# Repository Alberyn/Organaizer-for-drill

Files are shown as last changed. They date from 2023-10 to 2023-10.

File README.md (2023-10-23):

# Organaizer-for-drill

### Исследование

**Дано**: Сверла различных диаметров от 1.5 до 10 мм, общее количество превышает 40 штук.

Исследование началось с просмотра различных вариантов органайзеров в интернета (маркетплейсы, подделки от любителей) посредством ввода в поисковике "органайзер для сверл". Анализ результатов вывел типичную структуру для любого найденого органайзера - создание отдельного отверстия для каждого сверла. Рассмотрим несколько типичных органайзера, отличающихся друг от друга, разве что формой.

| Существующие решения | Достоинства | Недостатки |
|---|---|---|
|[Круглый держатель для сверл](https://darxton.ru/catalog_item/organayzer-dlya-svyerl-0-13-mm-100-predmetov/)| Много отверстий, занимает меньше места чем прямоугольная форма| Долгое время печати, нет возможности использования фанеры |
|[Органайзер с крышкой](https://aliexpress.ru/item/1005006088691748.html?sku_id=12000035679458737&spm=.search_results.2.7a9a45b48rbVsu)| Простота, защита от пыли | Не хватает отсеков |
|[Органайзер из фанеры с гравировкой для диаметров](https://ishooter.ru/product/organaizer-pod-sverla-10-99-mm-red-force-derevo.html) | Минимализм и простота | Используемый вариант, неудобный захват сверл|

**Вывод**: Так как количество сверл в будущем изменится и заранее узнать их диаметр невозможно, то было решено доработать дизайн из "Органайзер из фанеры с гравировкой для диаметров" с удобным захватом и регулируемым размером отверстий

### Доска вдохновения

[Miro. Organaizer-for-drill](https://miro.com/app/board/uXjVNaxHn4c=/?share_link_id=504908036010)

### Скетчинг

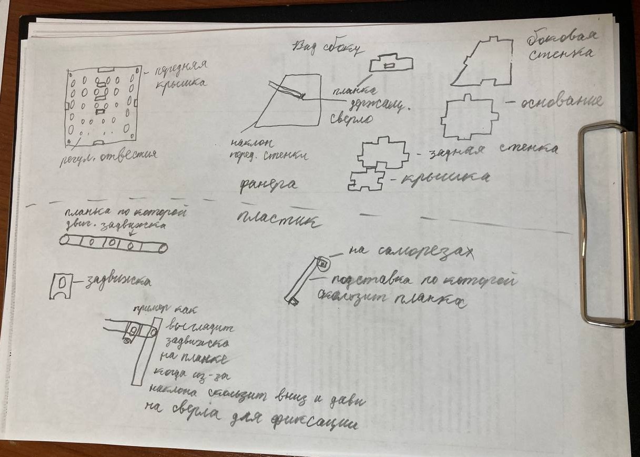
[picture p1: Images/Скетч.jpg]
sketch


Рисунок 1 - Наброски вида органайзера и его сборочных деталей

**Решение задачи**: Каркас из фанеры, мелкие (внутрение) детали из пластика, соединение будет осуществляться через саморезы.

### Моделирование и подготовка к печати

**Программное обеспечение**: SolidWorks, CorelDraw, Prusia Slicer

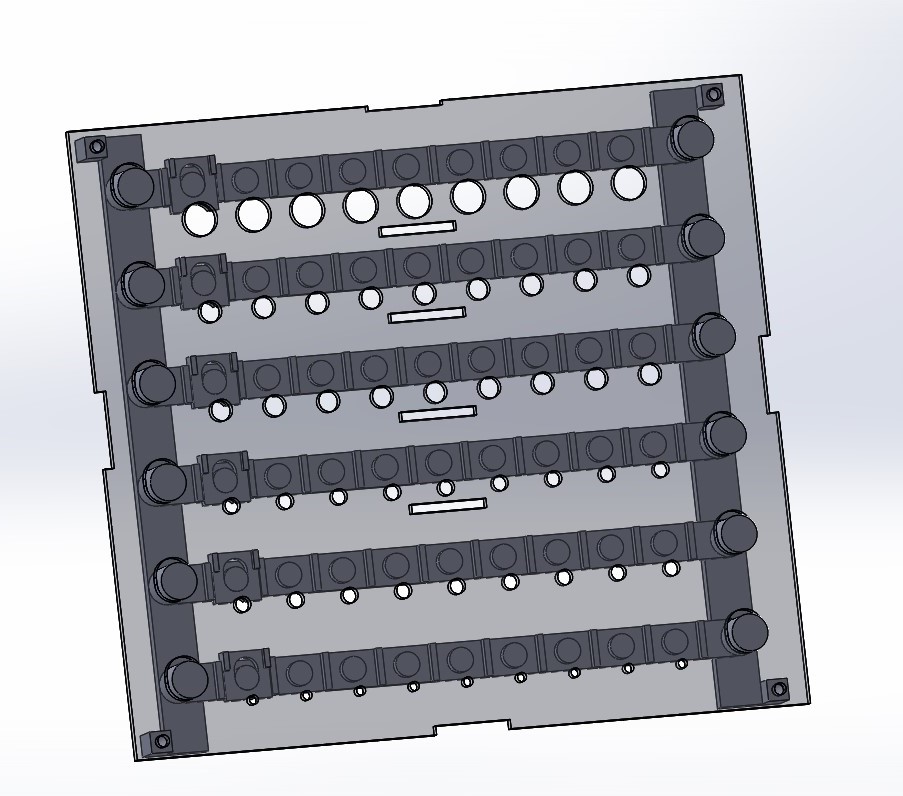
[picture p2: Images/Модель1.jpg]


Пример работы задвижки

Рисунок 2 - Трехмерная модель передней крышки с пластиковыми деталями

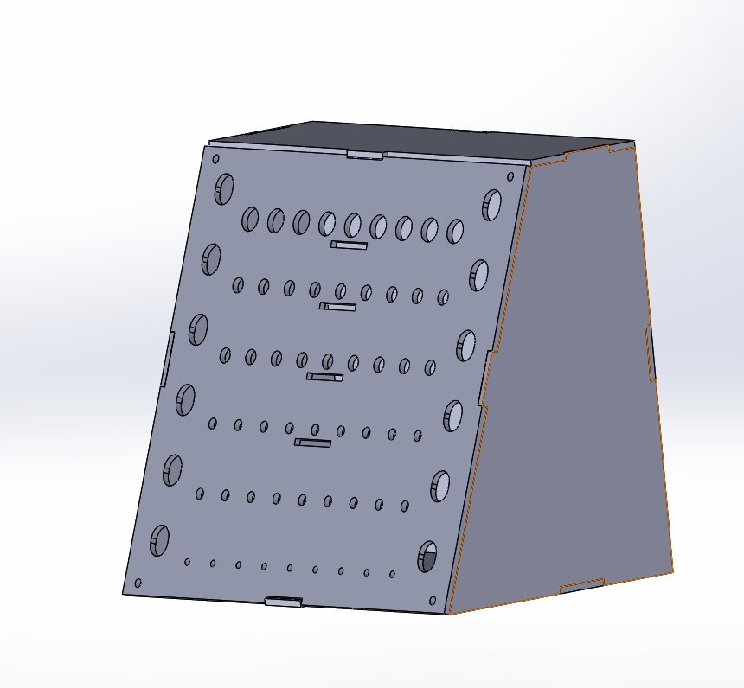
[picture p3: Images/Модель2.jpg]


Рисунок 3 - Трехмерная модель внешнего корпуса

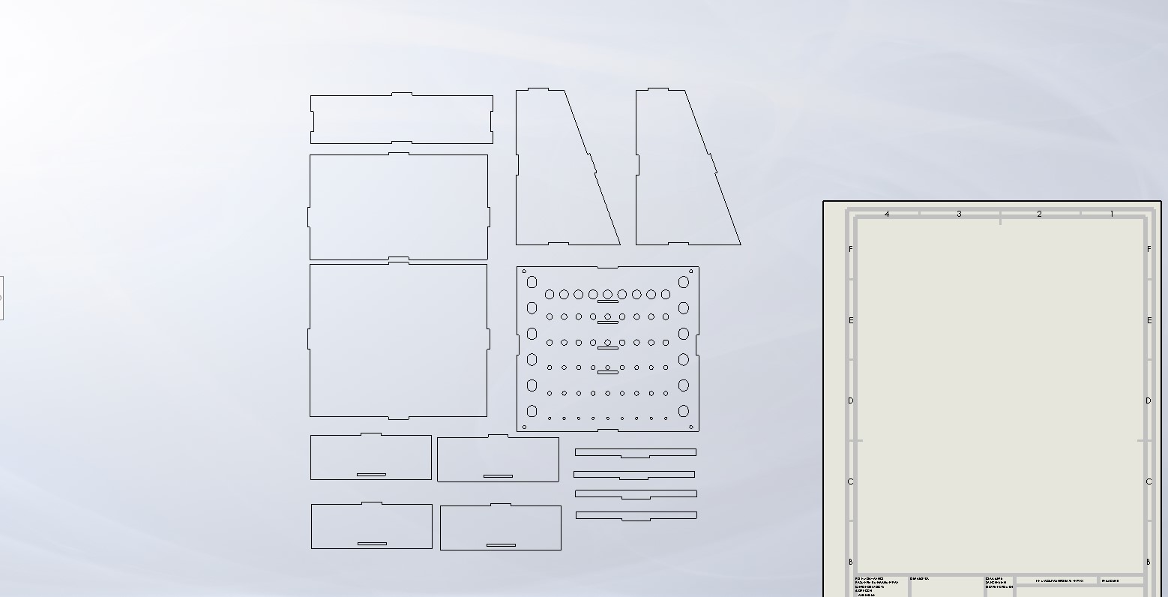
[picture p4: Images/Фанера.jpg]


Рисунок 4 - Чертеж каркаса из фанеры

Все модели для корпуса и деталей сделаны в программе Solidworks, модели корпуса экспортированы в формат DWG для последующего открытия в CorelDraw и отправки на печать. Модели деталей экспортированы в формат STL для последующего слайсинга в программе Prusa Slicer.

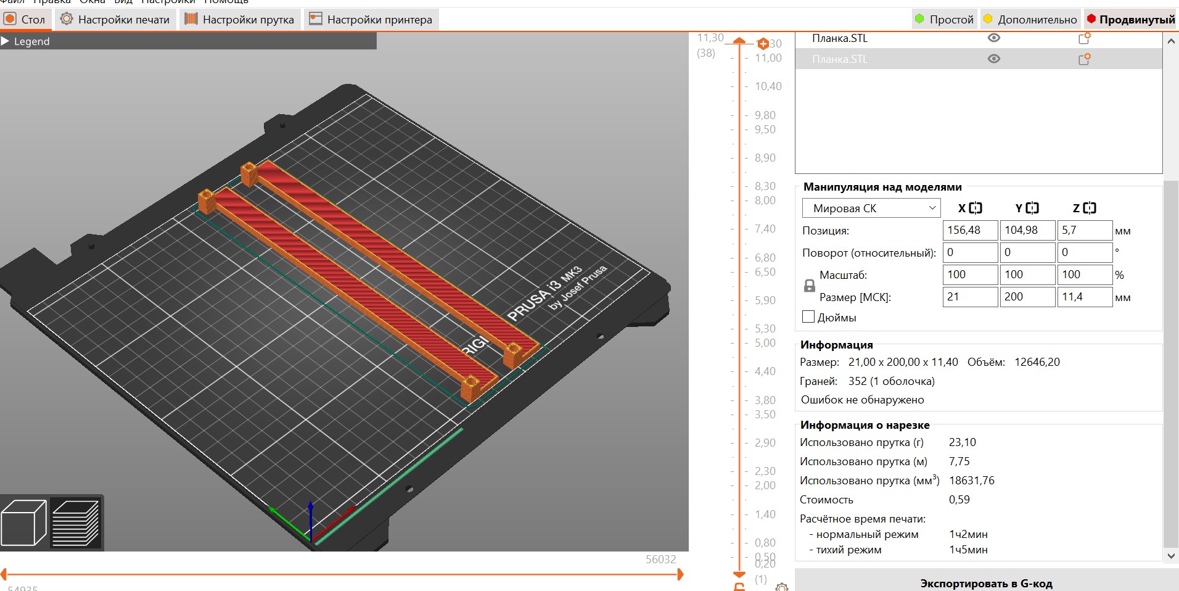
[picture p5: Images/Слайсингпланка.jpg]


Рисунок 5 - Создание G-кода для принтера

### Изготовление и сборка

| Материалы | Применение | Стоимость* | Оборудование | Время изготовления | 
|---|---|---|---|---|
|Лист фанеры 3 мм  | Каркас | 330 руб | Лазерный станок GCC Spirit GLS100 |6 минут |
|Filament PLA  | Внутрение детали | 145 руб | 3D-принтер Prusa i3 MK3 |6:20 часов |

*рассчитано, исходя из указанной в интернете стоимости материала

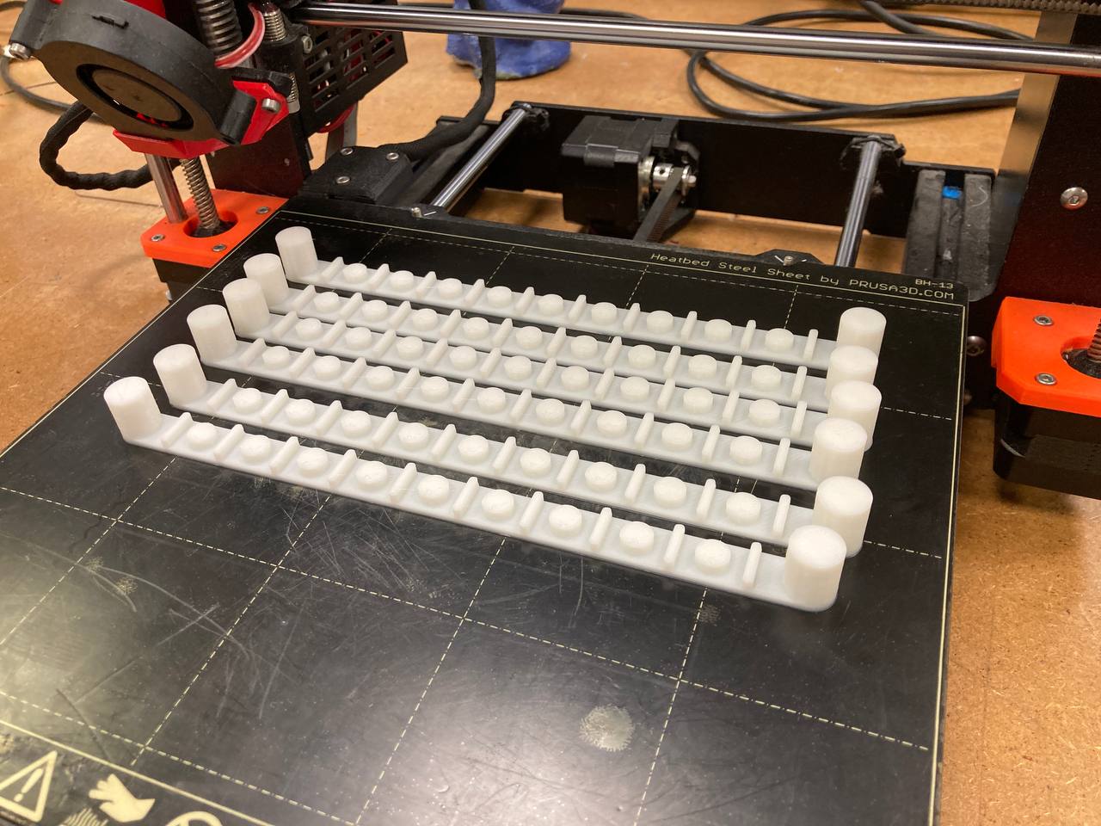
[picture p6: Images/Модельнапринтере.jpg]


Рисунок 6 - Полученный элемент органайзера с помощью 3D-принтера

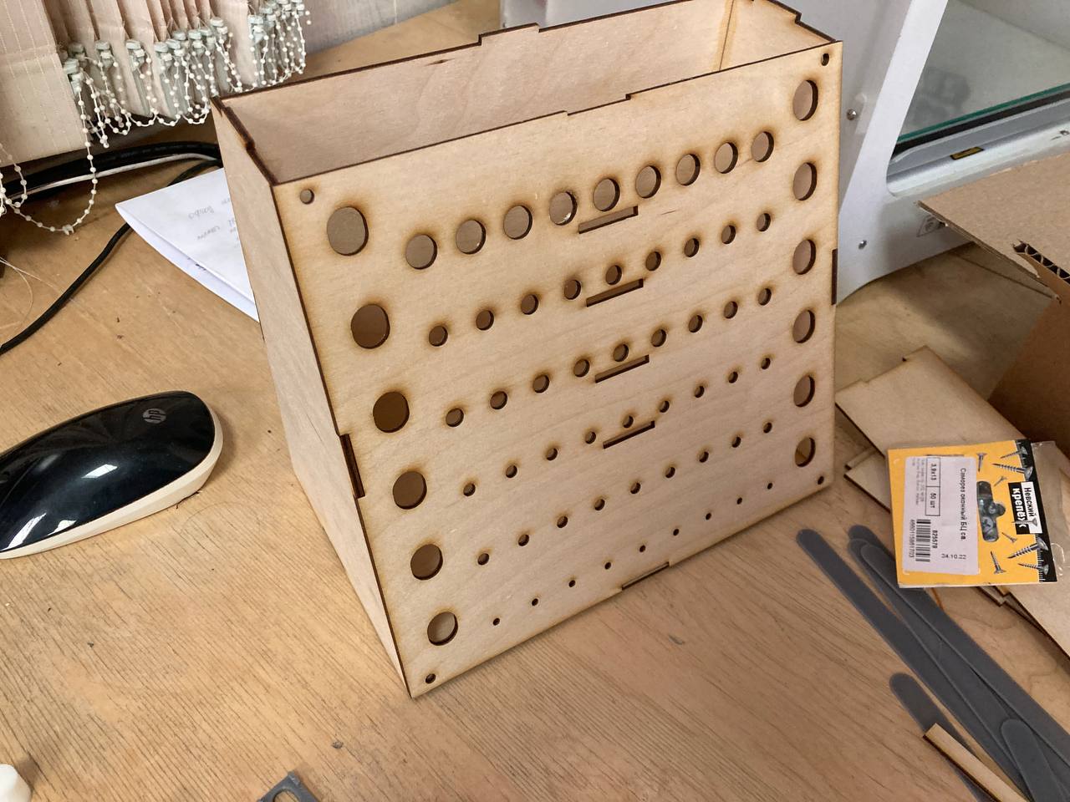
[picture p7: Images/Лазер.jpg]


Рисунок 7 - Полученные элементы органайзера с помощью лазерного станка

### Предварительный результат

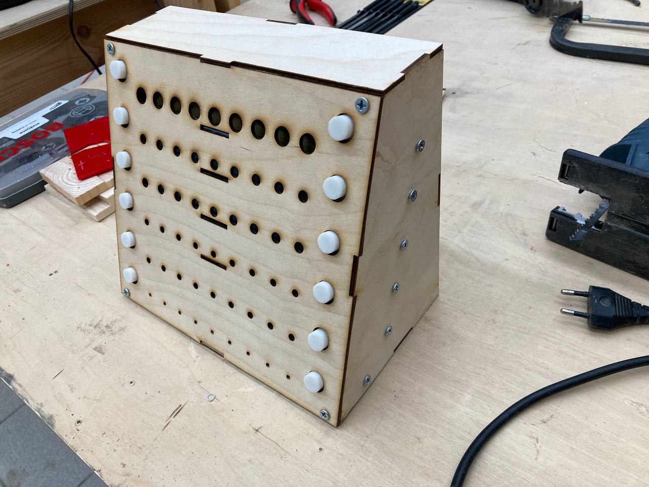
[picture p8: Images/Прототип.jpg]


Рисунок 8 - Прототип будущего органайзера

### Тестирование:

Video
*Видео откроется в новой вкладке

### Вещи для доработки:
1. Обработать отверстия шлифовальной машинкой, расширив их, чтобы планки и задвижки скользи по пазам.
2. Нанести на стыки клей для фиксации.
3. Планки на передней стенке упираются в основание, нужно прорезать отверстия в основании.
4. Держатели из фанеры для сверл недостатчно фиксируют их для переноски и прочего, поэтому надо будет создать ячейки для каждого ряда сверл на принтере.
5. Маркировка диаметров.

**Моделирование**

Создание держателей для сверл каждого ряда, крепящиеся на боковые стены для большей прочности конструкции

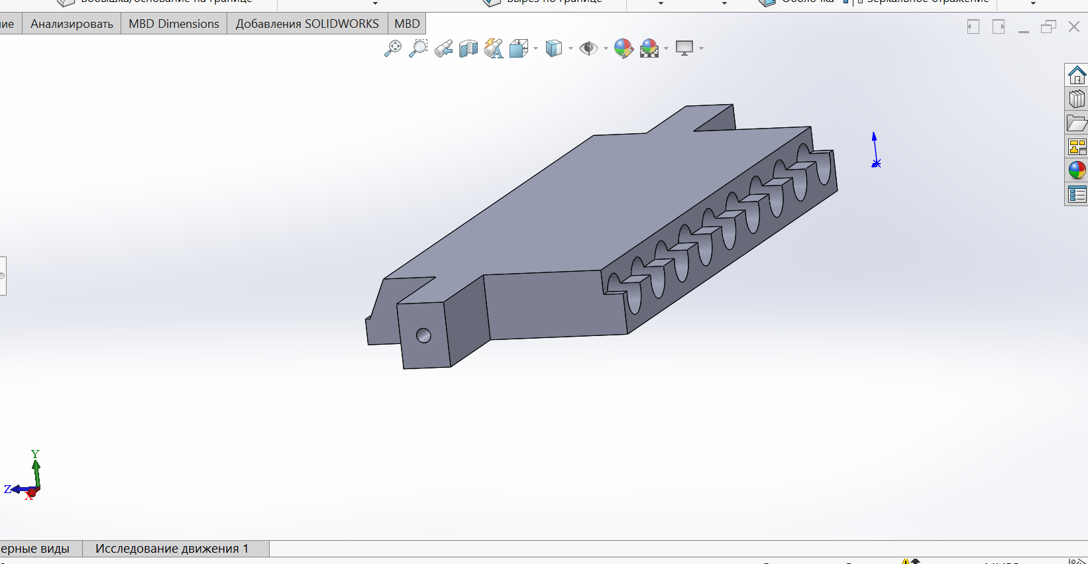
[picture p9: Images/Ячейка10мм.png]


Рисунок 9 - Трехмерная модель ячеек сверл с 10 мм радиусом

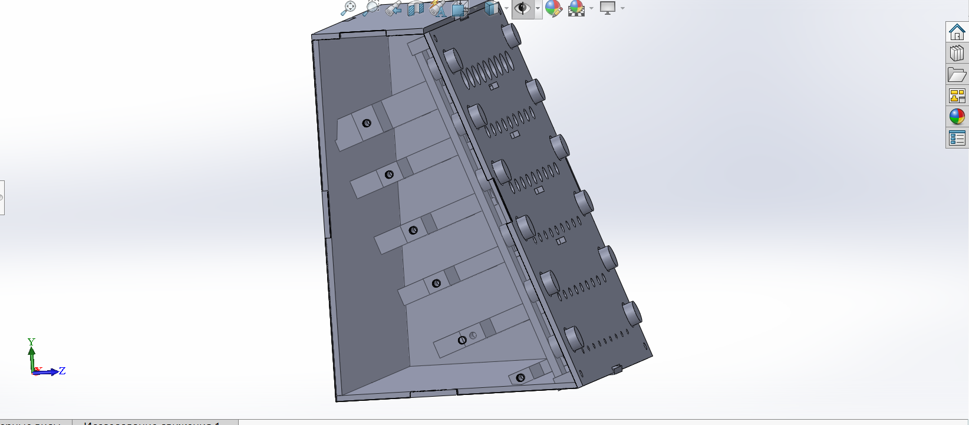
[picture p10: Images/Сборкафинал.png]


Рисунок 10 - Модель органайзера в разрезе

**Печать новых компонентов**

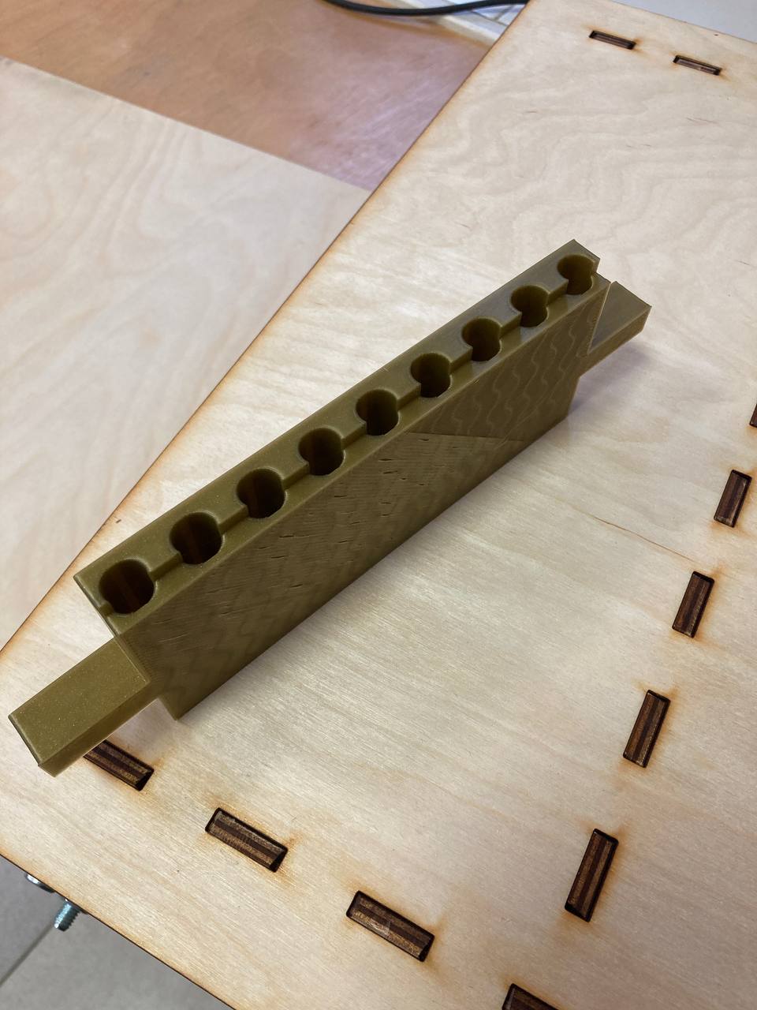
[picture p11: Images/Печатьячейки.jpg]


Рисунок 11 - Готовая модель ячеек сверл с 10 мм радиусом

## Результат
Все стыки фанеры дополнительно обработаны клеем, после обработки отверстий детали без проблем проскальзывают как надо, новые ячейки для сверл придают необходимую фиксацию сверл, маркировка передней крышки проводилась маркером.

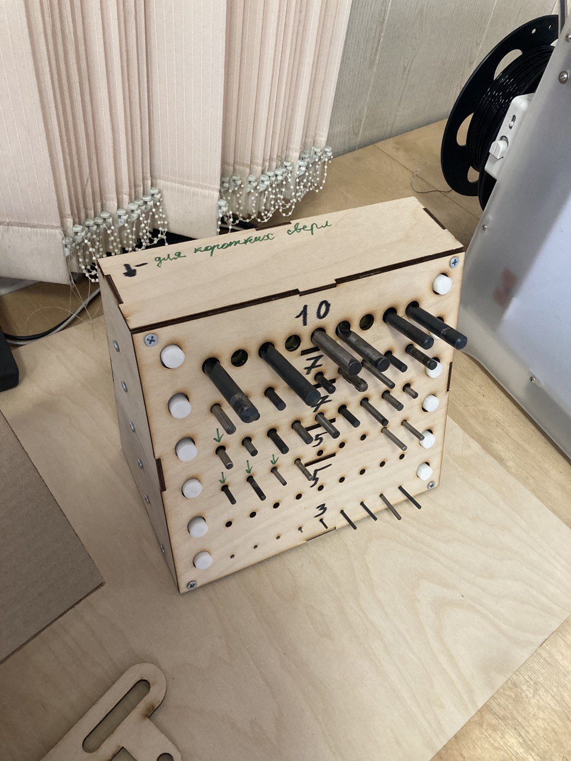
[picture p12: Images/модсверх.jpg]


Рисунок 12 - Органайзер (вид сверху)

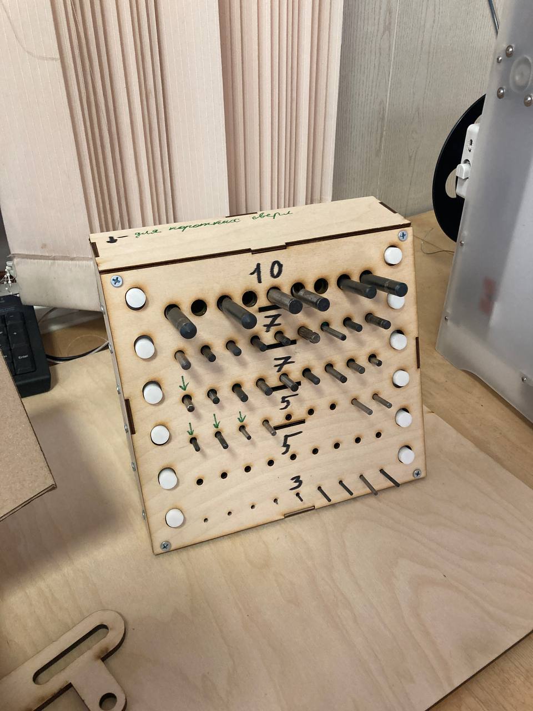
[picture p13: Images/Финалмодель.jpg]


Рисунок 13 - Органайзер (вид спереди)

**Тестирование:**

[Финальный результат](https://drive.google.com/file/d/1s3_rQBjPkMFttOHKlrNmcRscF6AJz6oU/view?usp=share_link)

## Оценка сборки
1. Задвижки не работают как задумывались, им не хватает веса или нажимающего усиллия на сверла;
2. Было не достаточно проверок сборки на пересечения, пришлось вырезать в корпусе отверстия, чтобы влезло все;
3. Нужны маркировки под каждое сверло для быстрого нахождения сверл, но это идет против концепции универсального отверстия.

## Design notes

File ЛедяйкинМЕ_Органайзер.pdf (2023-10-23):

### МИНИСТЕРСТВО ОБРАЗОВАНИЯ И НАУКИ РОССИЙСКОЙ ФЕДЕРАЦИИ

### ФЕДЕРАЛЬНОЕ ГОСУДАРСТВЕННОЕ АВТОНОМНОЕ УЧРЕЖДЕНИЕ ВЫСШЕГО ОБРАЗОВАНИЯ

### «Национальный исследовательский технологический

### университет «МИСиС»

ИНСТИТУТ | ЭКОТЕХНОЛОГИЙ И ИНЖИНИРИНГА
КАФЕДРА | МЕТАЛЛОВЕДЕНИЕ ЦВЕТНЫХ МЕТАЛЛОВ
НАПРАВЛЕНИЕ | 15.04.02 Технологические машины и оборудование

Практика цифрового производства

### на тему: “Органайзер для сверл”

Студент: Ледяйкин М.Е.

### Группа: МТМО-23-2

Проверил: Тавитов А.Г.

### Москва 2023

## Описание

Создание органайзера для сверл, описан процесс производства.

Исследование

Дано: Сверла различных диаметров от 1.5 до 10 мм, общее количество превышает

40 штук.

Исследование началось с просмотра различных вариантов органайзеров в

интернета (маркетплейсы, подделки от любителей) посредством ввода в поисковике

"органайзер для сверл". Анализ результатов вывел типичную структуру для любого

найденого органайзера - создание отдельного отверстия для каждого сверла. Рассмотрим

несколько типичных органайзера, отличающихся друг от друга, разве что формой.

Существующие решения | Достоинства | Недостатки
| Много отверстий, занимает меньше места чем прямоугольная форма | Долгое время печати, нет возможности использования фанеры
| Простота, защита от пыли | Не хватает отсеков

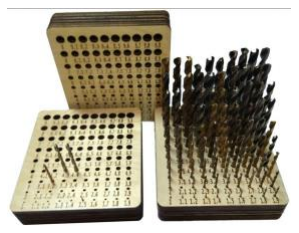
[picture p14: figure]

| Минимализм и простота | Используемый вариант, неудобный захват сверл

Вывод: Так как количество сверл в будущем изменится и заранее узнать их

диаметр невозможно, то было решено доработать дизайн из "Органайзер из фанеры с

гравировкой для диаметров" с удобным захватом и регулируемым размером отверстий

## Доска вдохновения

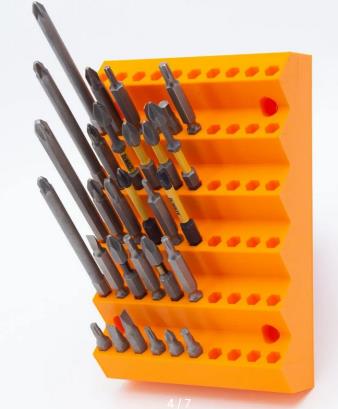
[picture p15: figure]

Рисунок 1 – Вдохновение для наклона сверл

## Скетчинг

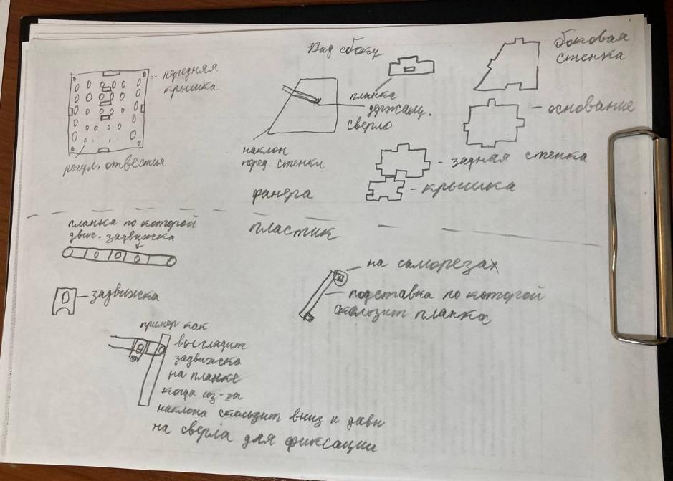
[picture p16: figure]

Рисунок 1 - Наброски вида органайзера и его сборочных деталей

Решение задачи: Каркас из фанеры, мелкие (внутренние) детали из пластика,

соединение будут осуществляться через саморезы.

## Моделирование и подготовка к печати

Программное обеспечение: SolidWorks, CorelDraw, Prusia Slicer

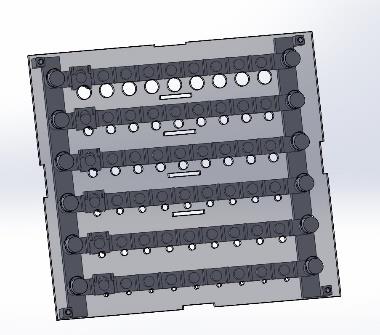
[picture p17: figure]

Рисунок 2 - Трехмерная модель передней крышки с пластиковыми деталями

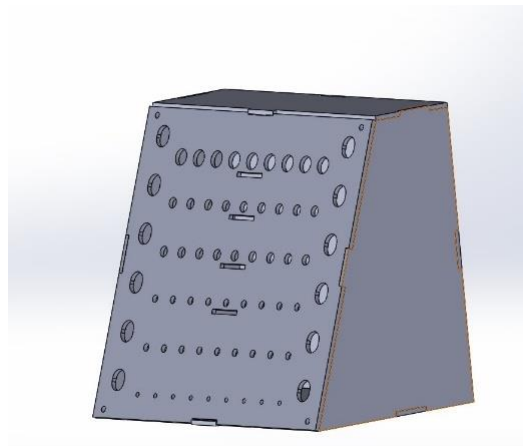
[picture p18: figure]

Рисунок 3 - Трехмерная модель внешнего корпуса

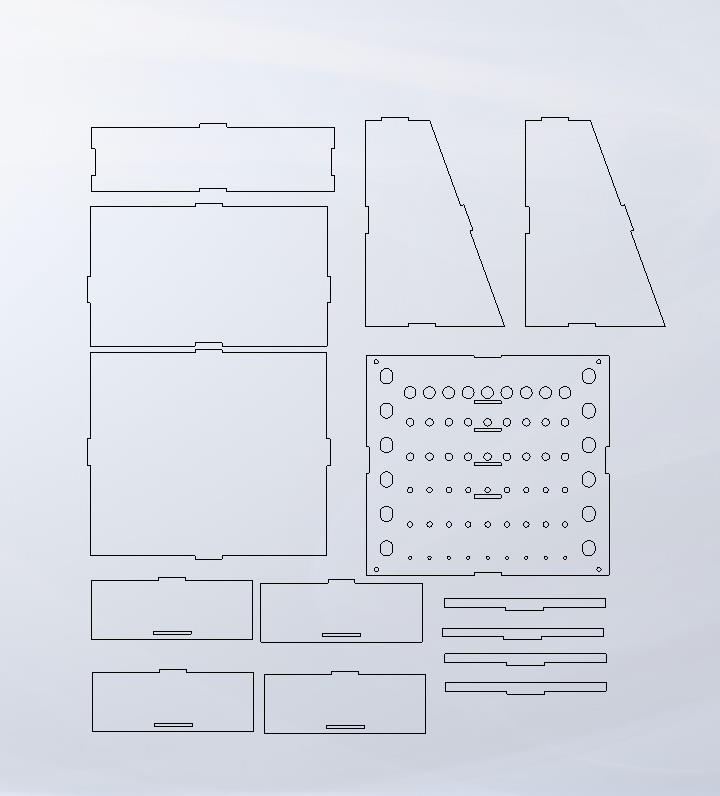
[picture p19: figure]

Рисунок 4 - Чертеж каркаса из фанеры

Все модели для корпуса и деталей сделаны в программе Solidworks, модели

корпуса экспортированы в формат DWG для последующего открытия в CorelDraw и

отправки на печать. Модели деталей экспортированы в формат STL для последующего

слайсинга в программе Prusa Slicer.

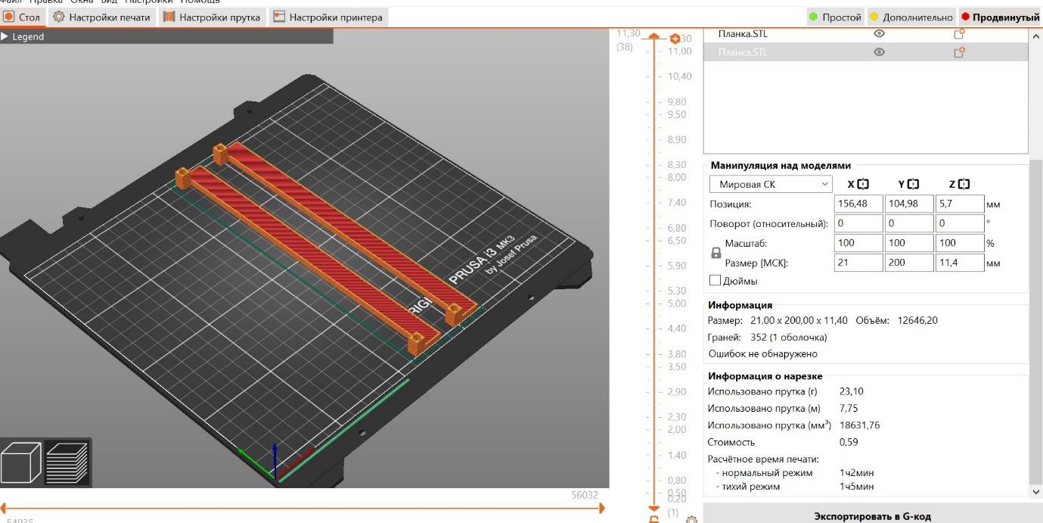
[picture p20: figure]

Рисунок 5 - Создание G-кода для принтера

## Изготовление и сборка

Материалы | Применение | Стоимость* | Оборудование | Время изготовления
Лист фанеры 3 мм | Каркас | 330 руб | | Лазерный станок GCC Spirit GLS100 | 6 минут
Filament PLA | Внутрение детали | 145 руб | 3D-принтер Prusa i3 MK3 | 6:20 часов

*рассчитано, исходя из указанной в интернете стоимости материала

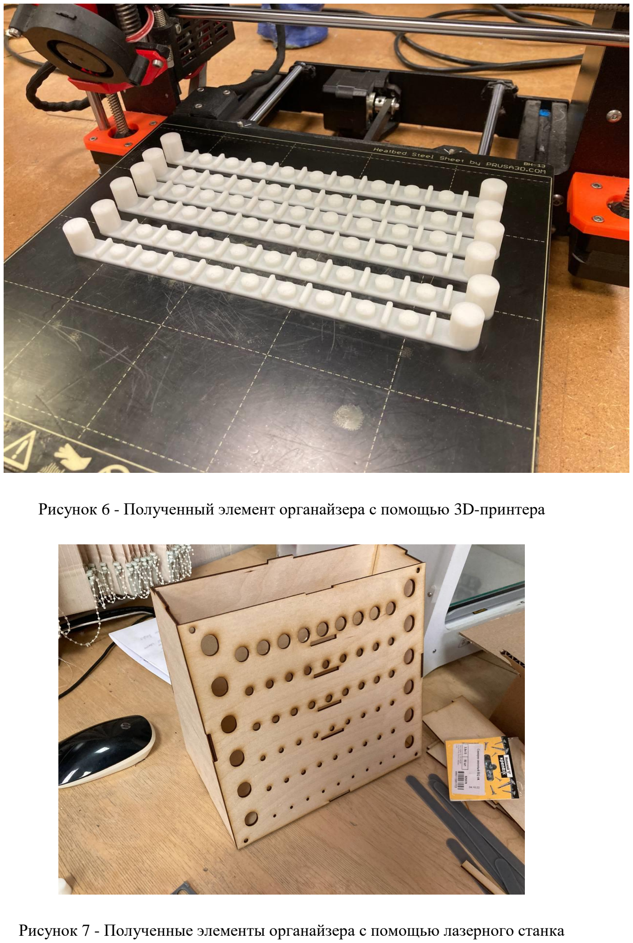
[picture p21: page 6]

Рисунок 6 - Полученный элемент органайзера с помощью 3D-принтера

Рисунок 7 - Полученные элементы органайзера с помощью лазерного станка

## Предварительный результат

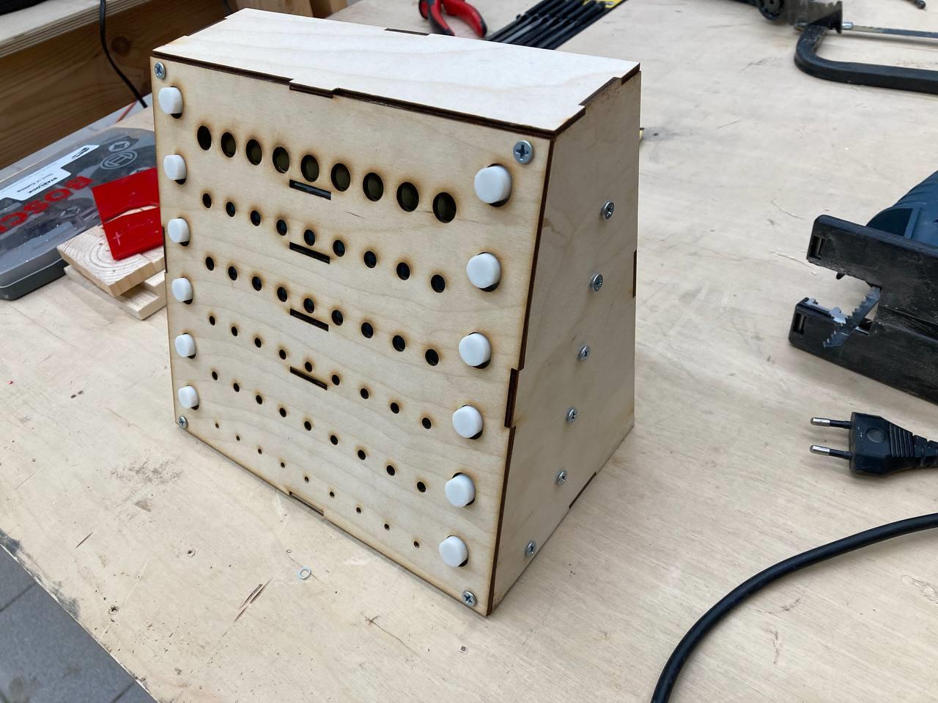
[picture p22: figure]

Рисунок 8 - Прототип будущего органайзера

## Тестирование

Видео на Githab

## Вещи для доработки

1. Обработать отверстия шлифовальной машинкой, расширив их, чтобы планки и задвижки скользи по пазам.
2. Нанести на стыки клей для фиксации.
3. Планки на передней стенке упираются в основание, нужно прорезать отверстия в основании.
4. Держатели из фанеры для сверл недостатчно фиксируют их для переноски и прочего, поэтому надо будет создать ячейки для каждого ряда сверл на принтере.
5. Маркировка диаметров.

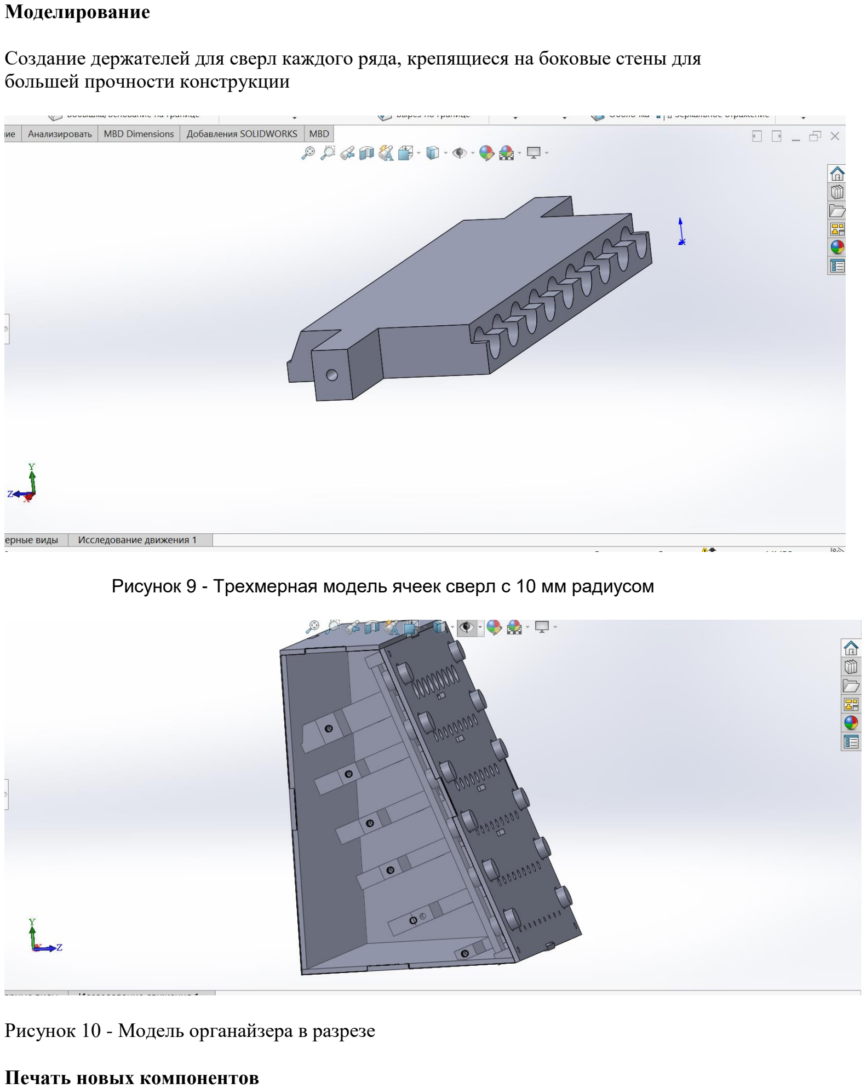
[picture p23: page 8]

Моделирование

Создание держателей для сверл каждого ряда, крепящиеся на боковые стены для большей прочности конструкции

Рисунок 9 - Трехмерная модель ячеек сверл с 10 мм радиусом

Рисунок 10 - Модель органайзера в разрезе

Печать новых компонентов

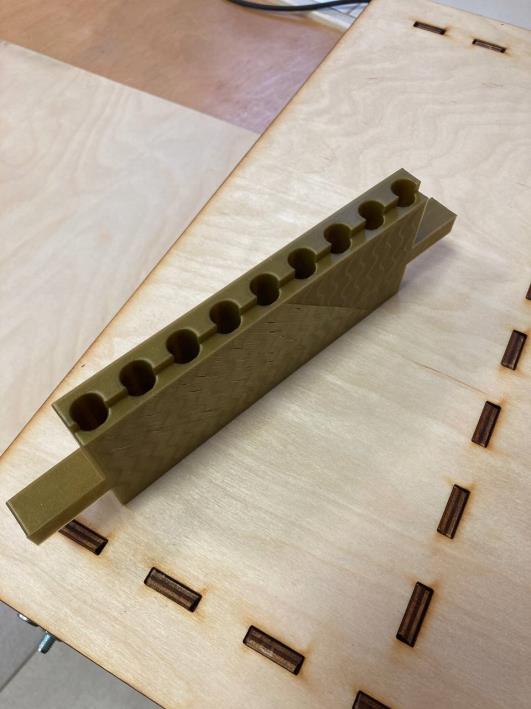
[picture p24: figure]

Рисунок 11 - Готовая модель ячеек сверл с 10 мм радиусом

## Результат (https://github.com/Alberyn/Organaizer-for-drill/blob/main/README.md#результат)

Все стыки фанеры дополнительно обработаны клеем, после обработки отверстий

детали без проблем проскальзывают как надо, новые ячейки для сверл придают

необходимую фиксацию сверл, маркировка передней крышки проводилась маркером.

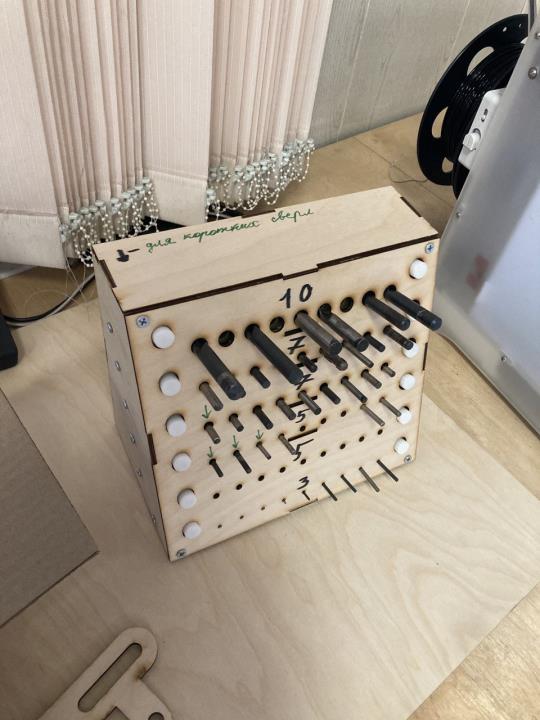
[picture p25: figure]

Рисунок 12 - Органайзер (вид сверху)

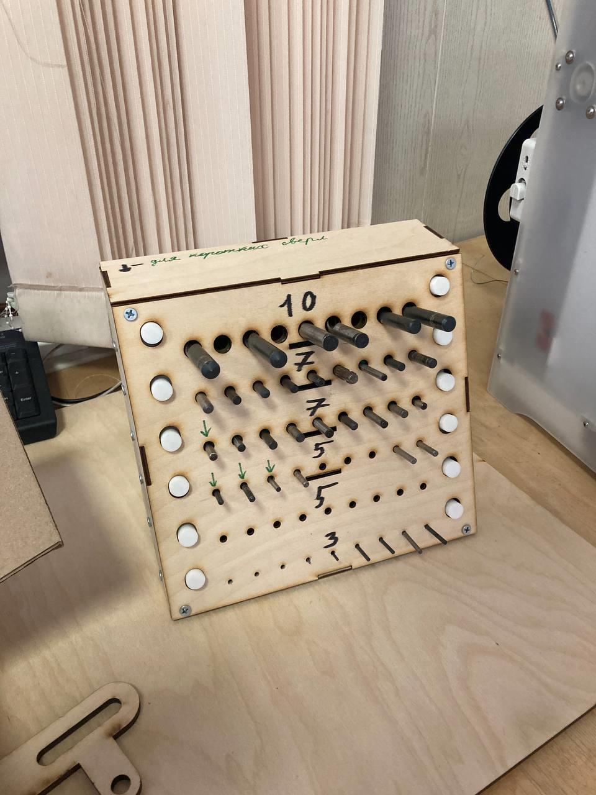
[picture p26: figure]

Рисунок 13 - Органайзер (вид спереди)

## Тестирование

Финальный результат (https://drive.google.com/file/d/1s3_rQBjPkMFttOHKlrNmcRscF6AJz6oU/view?usp=share_link)

Оценка сборки (https://github.com/Alberyn/Organaizer-for-drill/blob/main/README.md#оценка-сборки)

1) Задвижки не работают как задумывались, им не хватает веса или

нажимающего усиллия на сверла;

2) Было не достатчно проверок сборки на персечения, пришлось вырезать в

корпусе отверстия, чтобы влезло все;

3) Нужны маркировки под каждое сверло для быстрого нахождения сверл, но

это идет против концепции универсального отверстия.

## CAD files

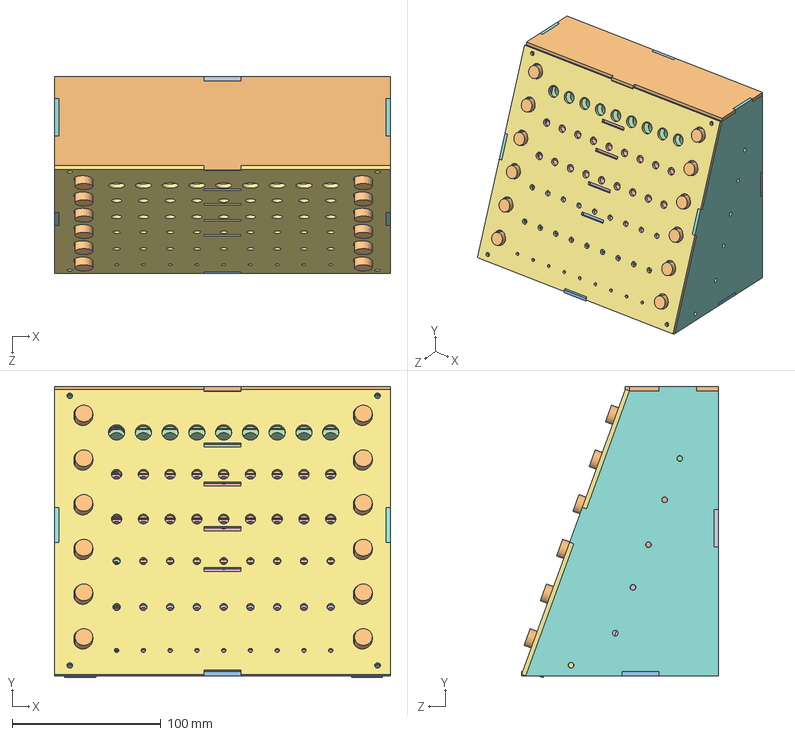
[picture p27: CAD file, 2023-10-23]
CAD/Сборка2.SLDASM
226.0 x 195.9 x 132.8 mm
Планка x 2
направляющая 3-5-7-9(10)мм x 6
Задвижка 3мм
Задвижка 5мм x 2
Задвижка 7мм x 2
Задвижка 11мм
Перед крышка
Боковая стенка x 2
Задняя стенка
крышка
Основание
Ячейки10мм
Ячейки7мм x 2
Ячейки5мм x 2
Ячейки3мм

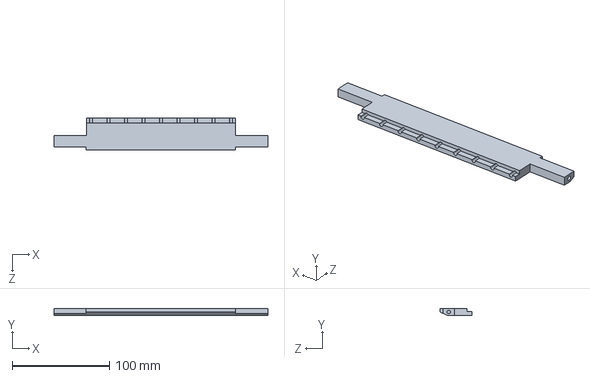
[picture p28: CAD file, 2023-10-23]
CAD/Ячейки3мм.SLDPRT
220.0 x 7.00 x 33.0 mm

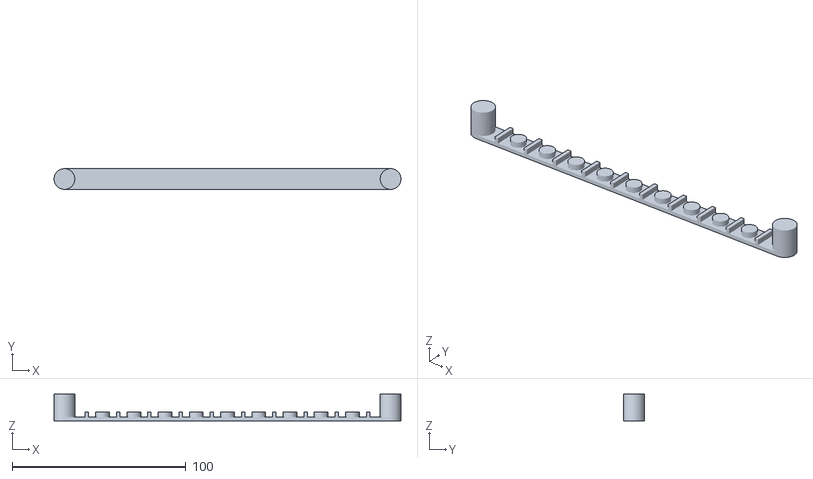
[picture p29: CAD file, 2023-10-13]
CAM/направляющая 3-5-7-9(10)мм.STL
200.0 x 12.0 x 15.3

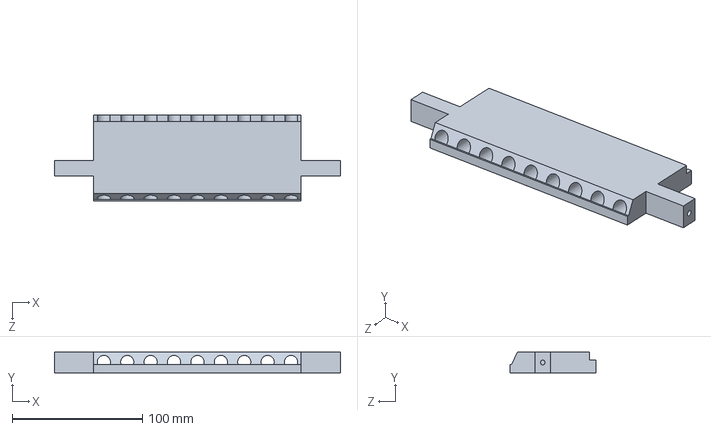
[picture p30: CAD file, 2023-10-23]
CAD/Ячейки10мм.SLDPRT
220.0 x 16.0 x 66.2 mm

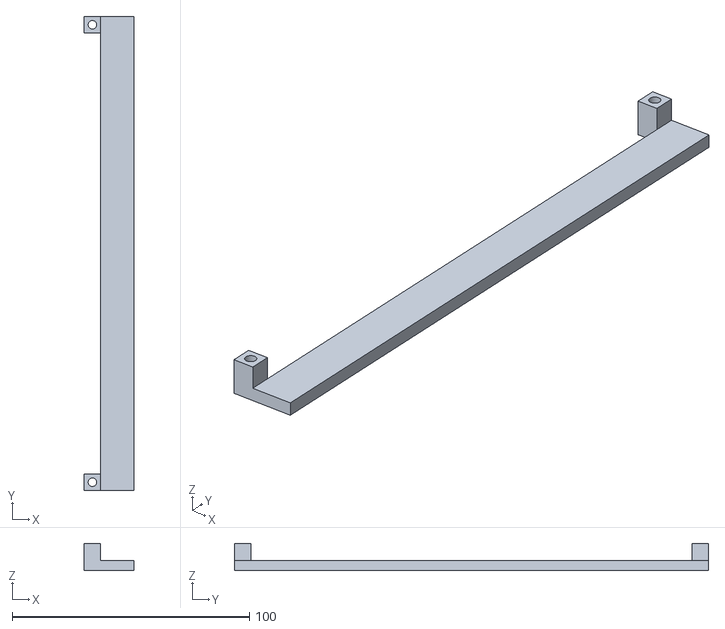
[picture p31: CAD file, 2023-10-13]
CAM/Планка.STL
21.0 x 200.0 x 11.4

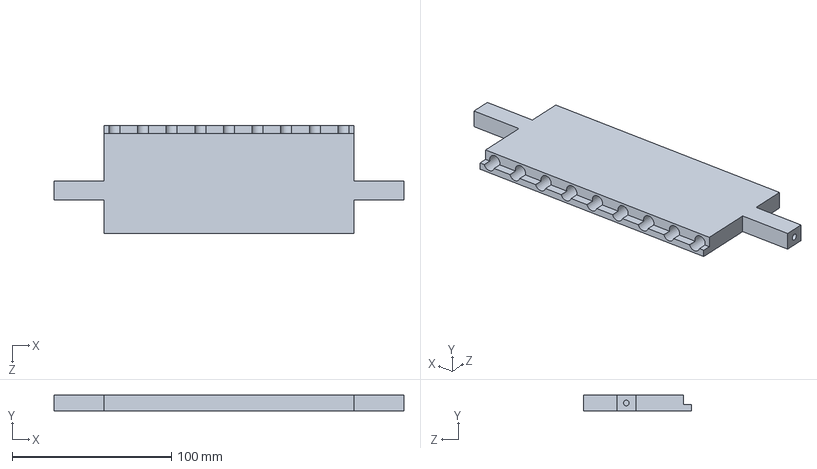
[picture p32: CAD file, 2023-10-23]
CAD/Ячейки7мм.SLDPRT
220.0 x 10.0 x 68.0 mm

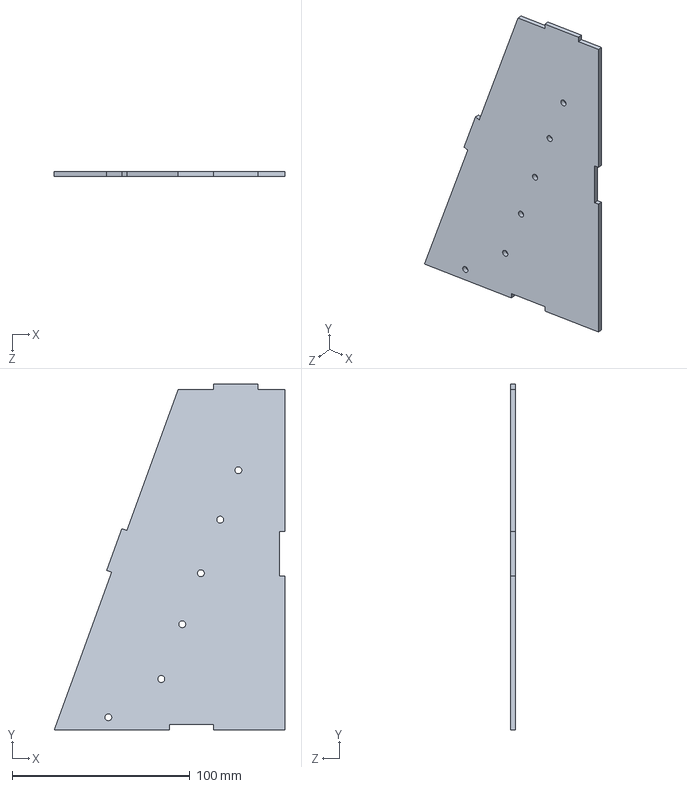
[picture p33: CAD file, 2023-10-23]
CAD/Боковая стенка.SLDPRT
129.8 x 194.7 x 3.00 mm

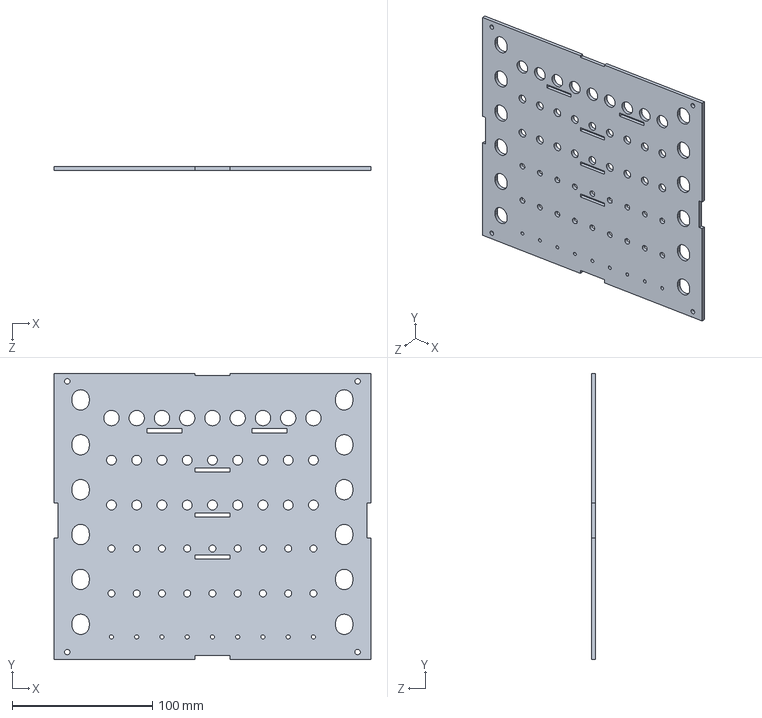
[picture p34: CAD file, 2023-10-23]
CAD/Перед крышка(измен).SLDPRT
226.0 x 204.0 x 3.00 mm

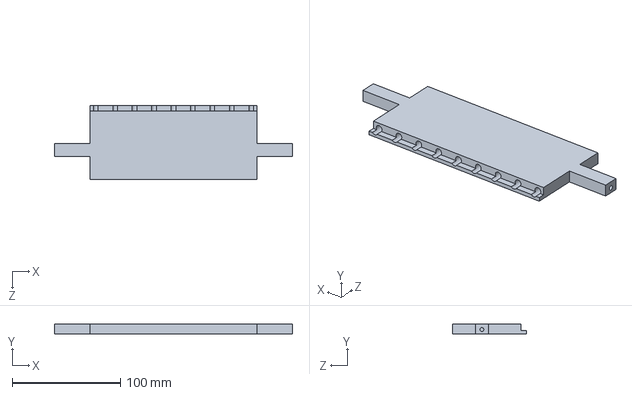
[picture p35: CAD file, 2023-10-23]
CAD/Ячейки5мм.SLDPRT
220.0 x 9.00 x 68.0 mm

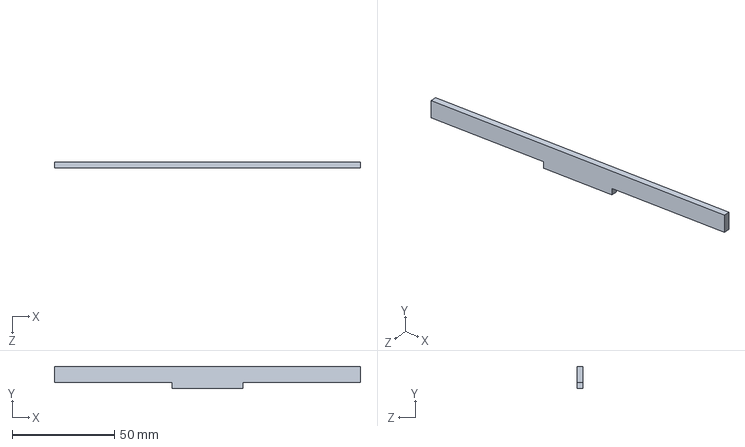
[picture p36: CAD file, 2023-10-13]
CAD/стопор.SLDPRT
150.0 x 11.0 x 3.00 mm

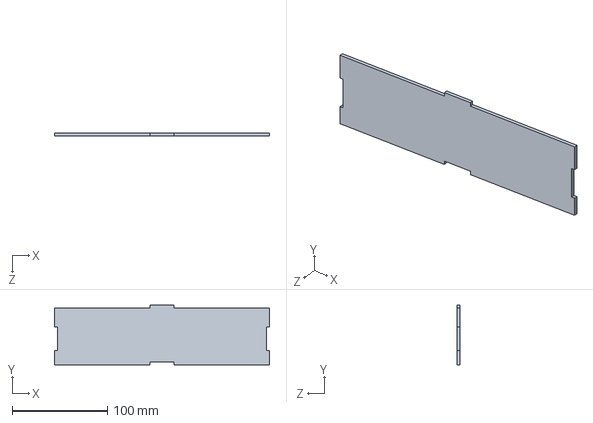
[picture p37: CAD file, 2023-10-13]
CAD/крышка.SLDPRT
226.0 x 63.0 x 3.00 mm

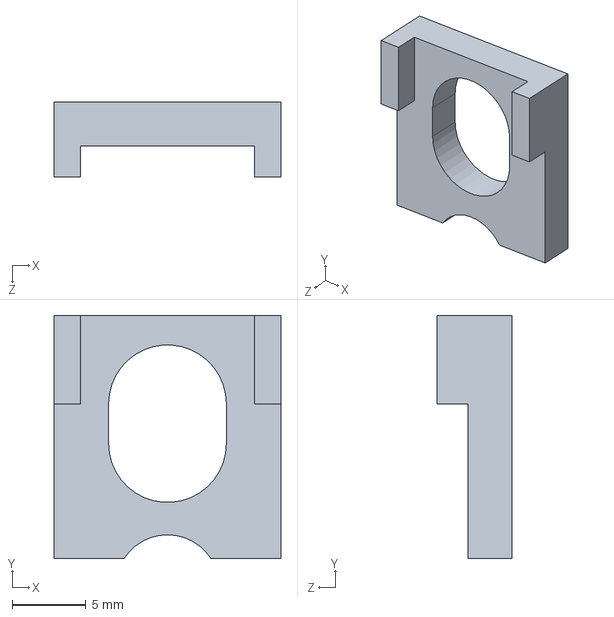
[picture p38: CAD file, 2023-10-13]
CAD/Задвижка 7мм.SLDPRT
15.4 x 16.5 x 5.10 mm

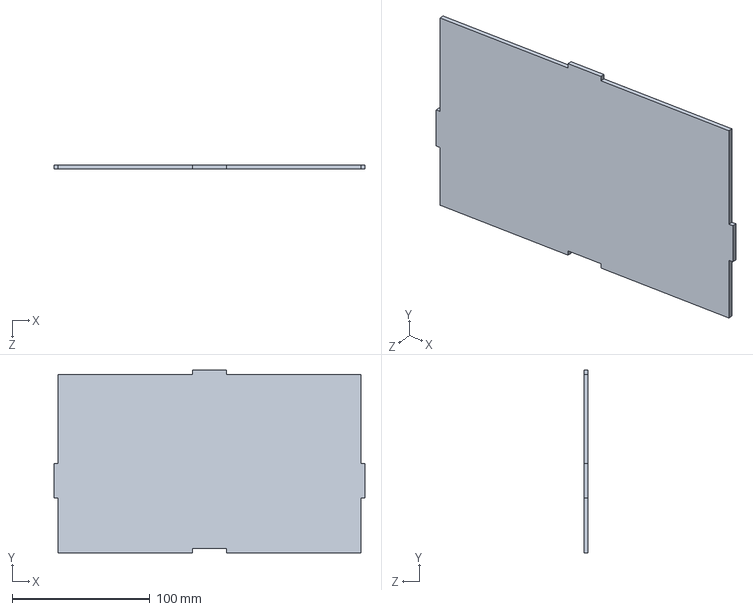
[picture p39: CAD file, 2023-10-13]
CAD/Основание.SLDPRT
226.0 x 132.8 x 3.00 mm

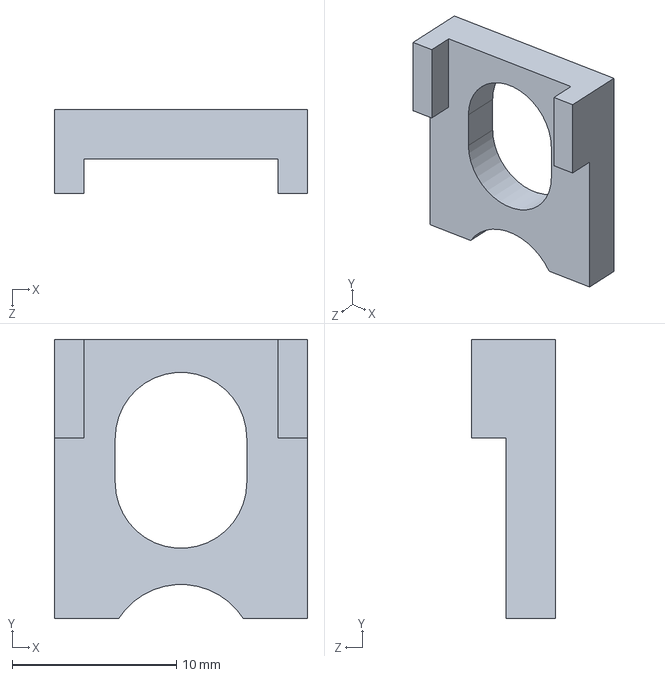
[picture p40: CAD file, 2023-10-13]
CAD/Задвижка 9мм.SLDPRT
15.4 x 17.0 x 5.10 mm

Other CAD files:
CAM/Fanera.DWG
CAD/Перед крышка.SLDPRT
CAD/направляющая 3-5-7-9(10)мм.SLDPRT
CAD/Задвижка 5мм.SLDPRT
CAD/Задвижка 11мм.SLDPRT
CAD/Задвижка 3мм.SLDPRT
CAD/Задняя стенка.SLDPRT
CAD/Планка.SLDPRT
CAD/Поддержка.SLDPRT

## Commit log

2023-10-13 Create CAD
    Папка для файлов Cad
2023-10-13 Create After
    После озарения
2023-10-13 Add files via upload
    Модели в Solidwork которые использовали для создание деталей на принтере и лазерной резкой
    [Боковая стенка.SLDPRT, Задвижка 11мм.SLDPRT, Задвижка 3мм.SLDPRT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]
2023-10-13 Add files via upload
    Файлы для печати на принтере- PLA-пластик
2023-10-13 Update README.md
    До скетчинга
2023-10-13 Update README.md
    До моделирования
2023-10-13 Update README.md
    Осталось только видео и фото готового изделия
2023-10-23 Update README.md
    Добавления оценки
